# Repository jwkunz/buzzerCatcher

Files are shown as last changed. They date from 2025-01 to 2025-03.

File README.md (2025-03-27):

# 4-Person Buzzer Game  

## Description  

This project includes the hardware design files and source code needed to build a four-person buzzer game from scratch.  

It was created as a volunteer activity associated with [The Church of Jesus Christ of Latter-day Saints](https://churchofjesuschrist.org "Church of Jesus Christ") to teach teenagers how to solder, 3D print, and program in C++.  

You are welcome to use and learn from this project under the **MIT License**.  

---

## How to Play  

1. **Connect the handles** using the RJ12 ports.  
2. **Power on the motherboard** by connecting it to a USB power supply.  
3. The game will play a **startup song**.  
4. The **slide switch toggles sound muting**.  
5. The game starts in the **reset state**—all handle LEDs should be **off**.  
6. **Ask a question.**  
7. Press the **motherboard button** to enable responses—handles will light up the **left LED**.  
8. Players **press and hold a handle button** to respond.  
   - The motherboard will play a sound.  
   - If two players press at the same time, the motherboard applies a **random tiebreaker**.  
   - Players can press the button **before** responses are enabled.  
9. The winning handle will light up the **right LED**.  
10. The player states their **answer**.  
11. **Judge and score manually**.  
12. Press the **motherboard button** to reset and go back to step **6**.  

---

## Code  

### Diagnostics  

Short test scripts for **buttons and LEDs**—useful for teaching coding basics.  

### Game  

The **Arduino project** implementing the game using the **FreeRTOS framework**.  

- Customize the `song_XXXXX` files to add **custom buzzer sounds**.  
- The main file for **Arduino compilation** is `game.ino`.  

---

## 3D Printed Components  

Designed in **FreeCAD**. `.stl` files for 3D printing are available in the corresponding component folders.  

### Case  

A **3D-printable enclosure** for the motherboard.  

### Handle  

A **3D-printable enclosure** for the four handles, each equipped with a button and LEDs. The handles connect to the motherboard via **RJ12 phone cables**.  

---

## PCB Design  

Designed in **KiCad**.  

- The **exports folder** contains:  
  - **Bill of materials (BOM)**  
  - **Gerber and drill files** for PCB manufacturing  
- Also includes:  
  - A `.step` model and **schematic printout** for circuit reference  
- **Note**: This repository does **not** include the full KiCad parts library required for board file recreation.  

---

## Cost Estimate  

At the time of publication:  

- **PCB and component costs**: $75 - $125 USD per board (varies based on order size; e.g., **Osh Park requires a minimum order of 3 PCBs**).  
- **3D printing material**: ~300g of **PLA** per system.  
- **Assembly time**:  
  - **Skilled labor**: ~2 hours  
  - **Beginners**: ~10 hours

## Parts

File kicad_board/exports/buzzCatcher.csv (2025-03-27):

Reference | Datasheet | Qty | Manufacturer_Name | Manufacturer_Part_Number | Description
A1 | http://www.mouser.com/pdfdocs/Gravitech_Arduino_Nano3_0.pdf | 1 |  | ABX00033 | Arduino Nano v3.x
IC1 | https://www.cuidevices.com/product/resource/ts02.pdf | 1 | Same Sky | TS02-66-60-BK-100-SCR-D | Tactile Switches 6 x 6 mm, 6 mm Act Height, 100 gf, Black, Short Crimped, Through Hole, SPST,
J1,J2,J3,J4,J5,J6,J7,J8 | https://datasheet.datasheetarchive.com/originals/distributors/Datasheets_SAMA/df0790d8aebb5882625d0f98b986e00d.pdf | 8 | Molex | 95501-2661 | 6/6 way r/a PCB thru hole data skt,1.5A Molex 6P/6C Right Angle Through Hole Female RJ12 UTP RJ12 Connector
J13,J14,J15,J16 | ~ | 4 |  | BC-66SS025F | RJ connector, 6P6C (6 positions 6 connected)
J17,J18,J19,J20 | https://cdn.amphenol-cs.com/media/wysiwyg/files/drawing/67996.pdf | 4 | Amphenol Communications Solutions | 67996-100HLF | BergStik<sup>&reg;</sup>, Board to Board connector, Unshrouded vertical header, Through Hole, Double Row, 0 Positions, 2.54 mm (0.100in) Pitch
J21 | ~ | 1 |  | UR050-010 | USB Micro Cable
J22 | ~ | 1 |  | PSAA05A-050QL6-R | USB Charger
LED1,LED2,LED3,LED4,LED5,LED6,LED7,LED8 | https://www.kingbrightusa.com/images/catalog/SPEC/WP7113ID5V.pdf | 8 | Kingbright | WP7113ID5V | Red LED with 5V resistor
LED9 | https://www.lumex.com/content/files/ProductAttachment/SSA-LXH1025GD.pdf | 1 | Lumex | SSA-LXH1025GD | LED Circuit Board Indicator LED Circuit Board Indicator Bar - 10 Wide, SIP Green (x 10) Diffused, Tinted 2.2V 25mA Rectangle with Flat Top 5.00mm x 2.50mm Through Hole
LS1 | https://www.cuidevices.com/product/resource/digikeypdf/cmt-1209-590t.pdf | 1 | Same Sky | CMT-1209-590T | Buzzers Transducer, Externally Driven Magnetic 5 V 65mA 2.048kHz 90dB @ 5V, 10cm Through Hole PC Pins
Q1,Q2 | https://datasheet.datasheetarchive.com/originals/distributors/Datasheets-24/DSA-462429.pdf | 2 | onsemi | BS170 | N-channel JFET,BF245A 2mA 30V,BP
R1,R2 | https://www.mouser.ch/datasheet/2/54/4100R-776985.pdf | 2 | Bourns | 4116R-1-121LF | BOURNS - 4116R-1-121LF - Fixed Network Resistor, 120 ohm, 4100R Series, 8 Elements, Isolated, DIP, 16 Pins
RN2 | https://www.bourns.com/data/global/pdfs/4100R.pdf | 1 | Bourns | 4116R-1-103FLF | Resistor Networks & Arrays 10K OHM 16 PIN 1%
S1 | https://www.ckswitches.com/media/1428/os.pdf | 1 | C & K COMPONENTS | OS102011MS2QS1 | SWITCH SLIDE SPDT 100MA 12V
SW1,SW2,SW3,SW4 | ~ | 4 |  | PV5S64019 | Push button switch, generic, two pins

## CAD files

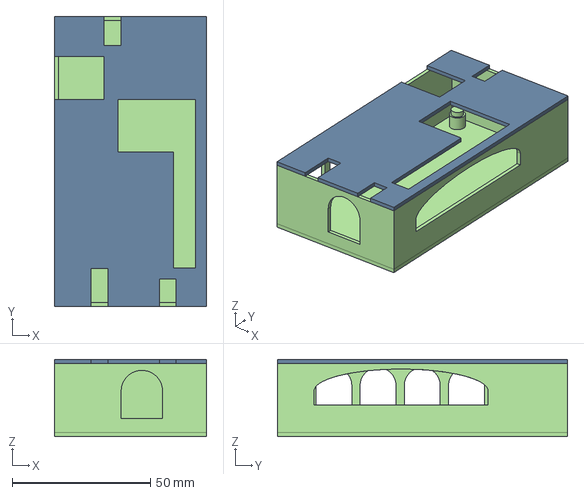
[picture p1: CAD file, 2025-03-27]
freecad_buzzer_case/buzzer_case.FCStd
55.0 x 105.0 x 28.0 mm
Lid

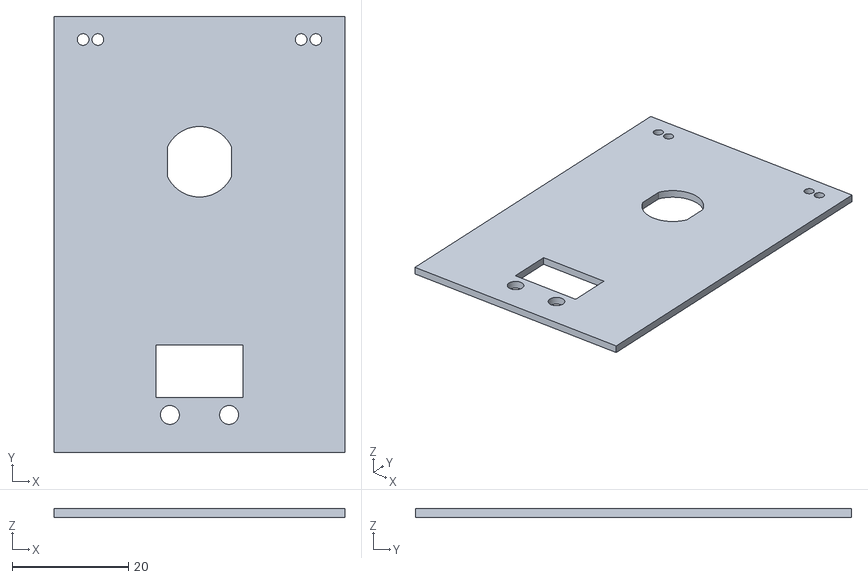
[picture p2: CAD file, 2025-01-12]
freecad_handle/handle-Lid.stl
50.0 x 75.0 x 1.50

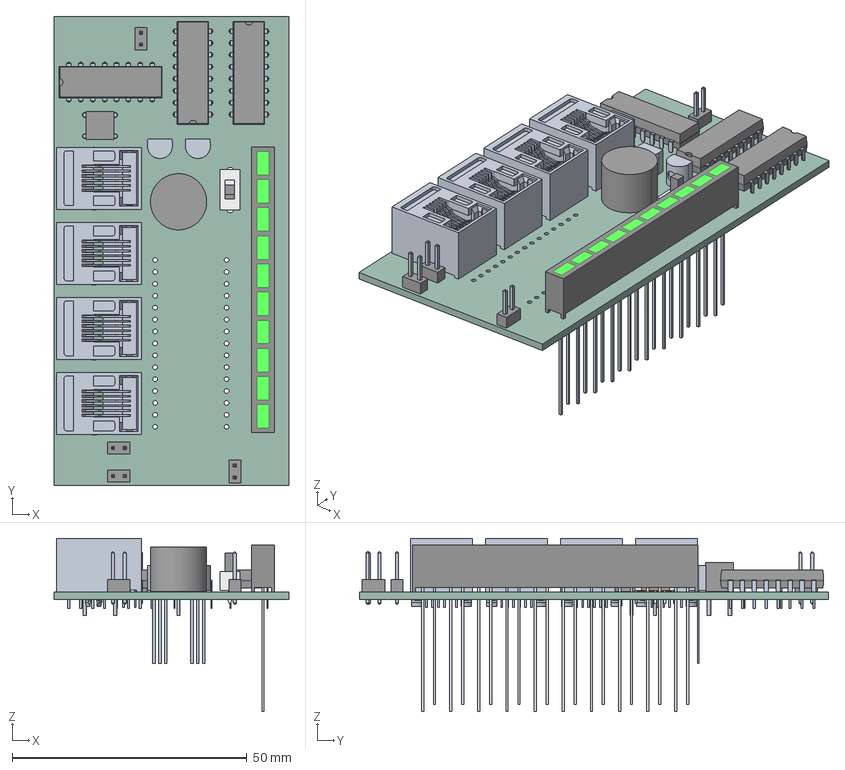
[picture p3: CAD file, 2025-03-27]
kicad_board/exports/buzzCatcher.step
50.0 x 100.0 x 37.0 mm
BC547BBU x 2
ASSEMBLY x 9
OS102011MS2QS1
SSA-LXH1025GD
buzzCatcher_PCB

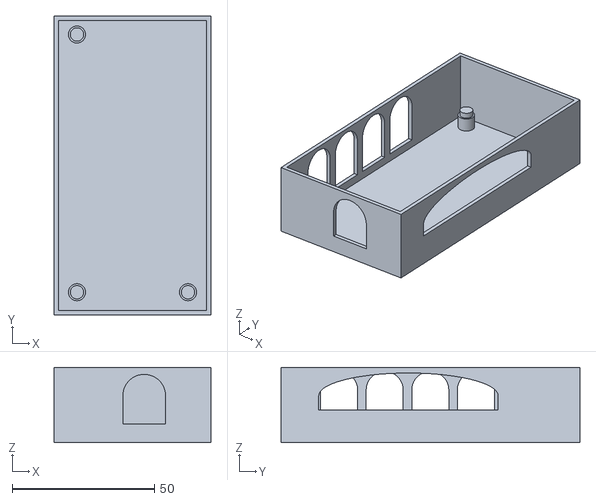
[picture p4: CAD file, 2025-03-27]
freecad_buzzer_case/buzzer_case-Body.stl
55.0 x 105.0 x 26.5

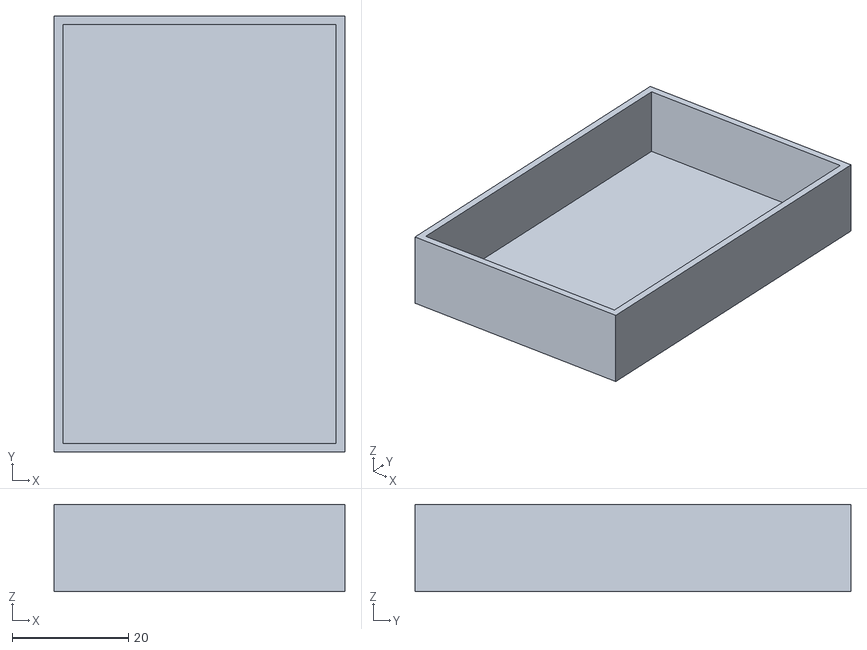
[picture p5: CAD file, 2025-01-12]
freecad_handle/handle-Case.stl
50.0 x 75.0 x 15.0

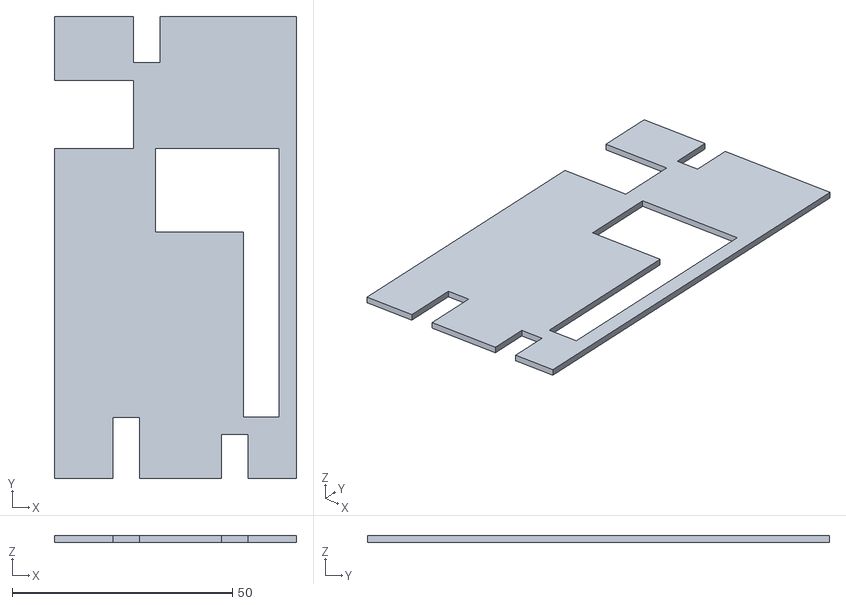
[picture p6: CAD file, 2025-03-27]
freecad_buzzer_case/buzzer_case-Lid.stl
55.0 x 105.0 x 1.50

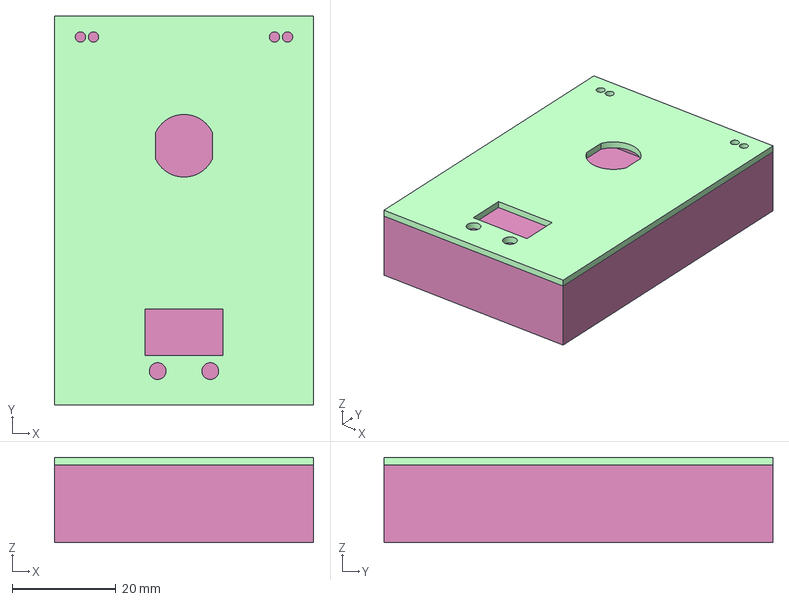
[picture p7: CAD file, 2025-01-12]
freecad_handle/handle.FCStd
50.0 x 75.0 x 16.5 mm
Lid
Case

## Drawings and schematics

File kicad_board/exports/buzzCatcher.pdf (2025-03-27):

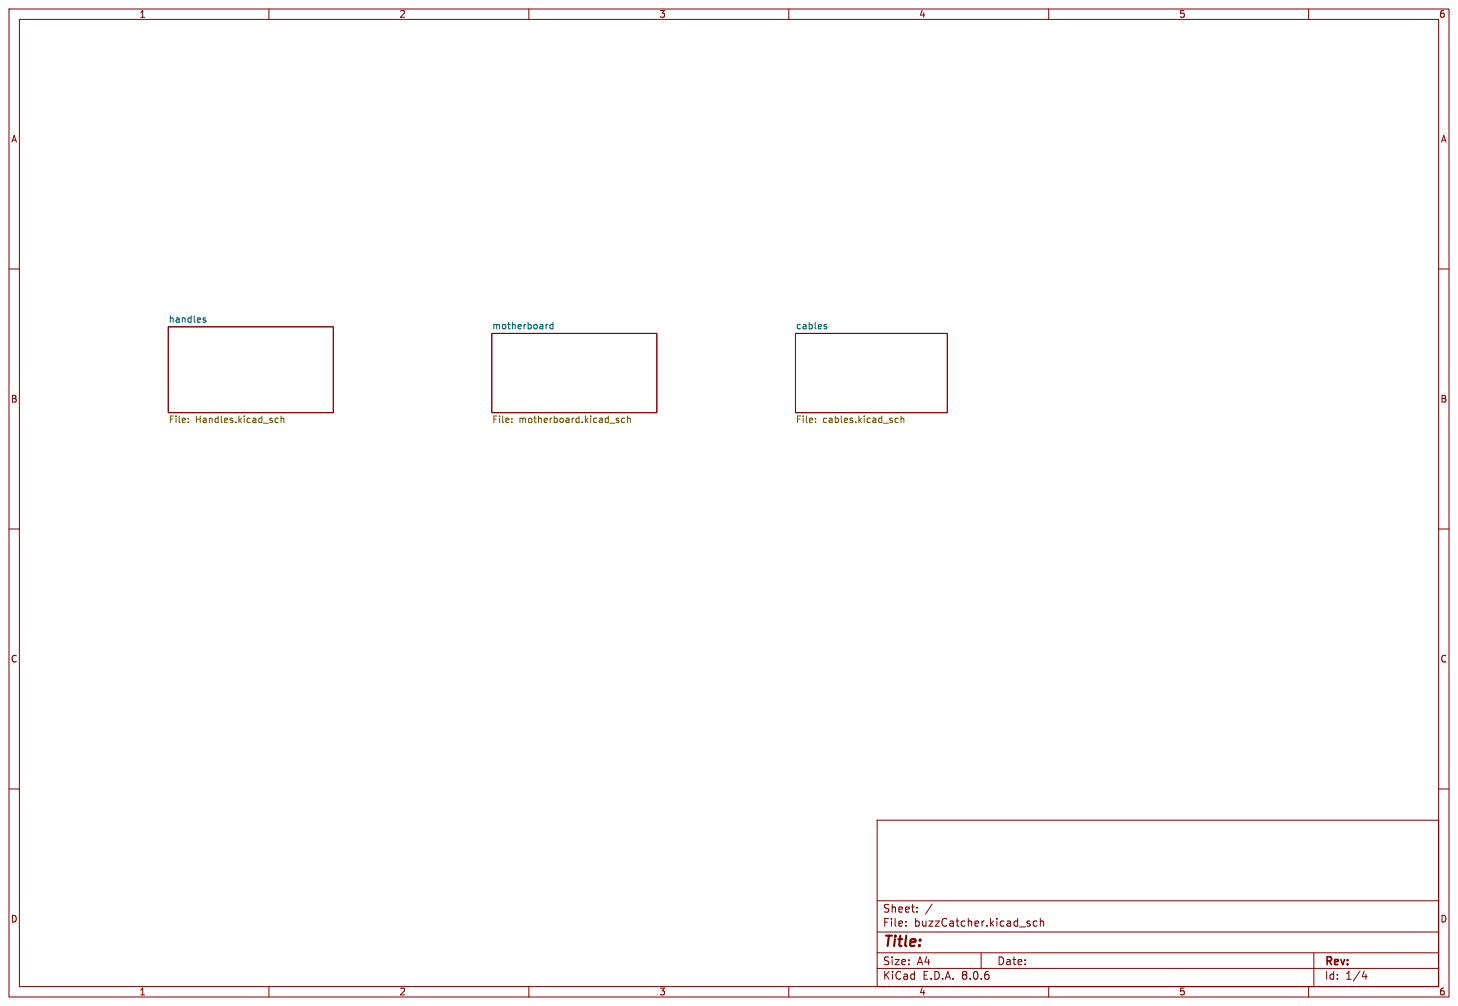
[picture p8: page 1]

Id: 1/4 Title: File: buzzCatcher.kicad_sch Sheet: /

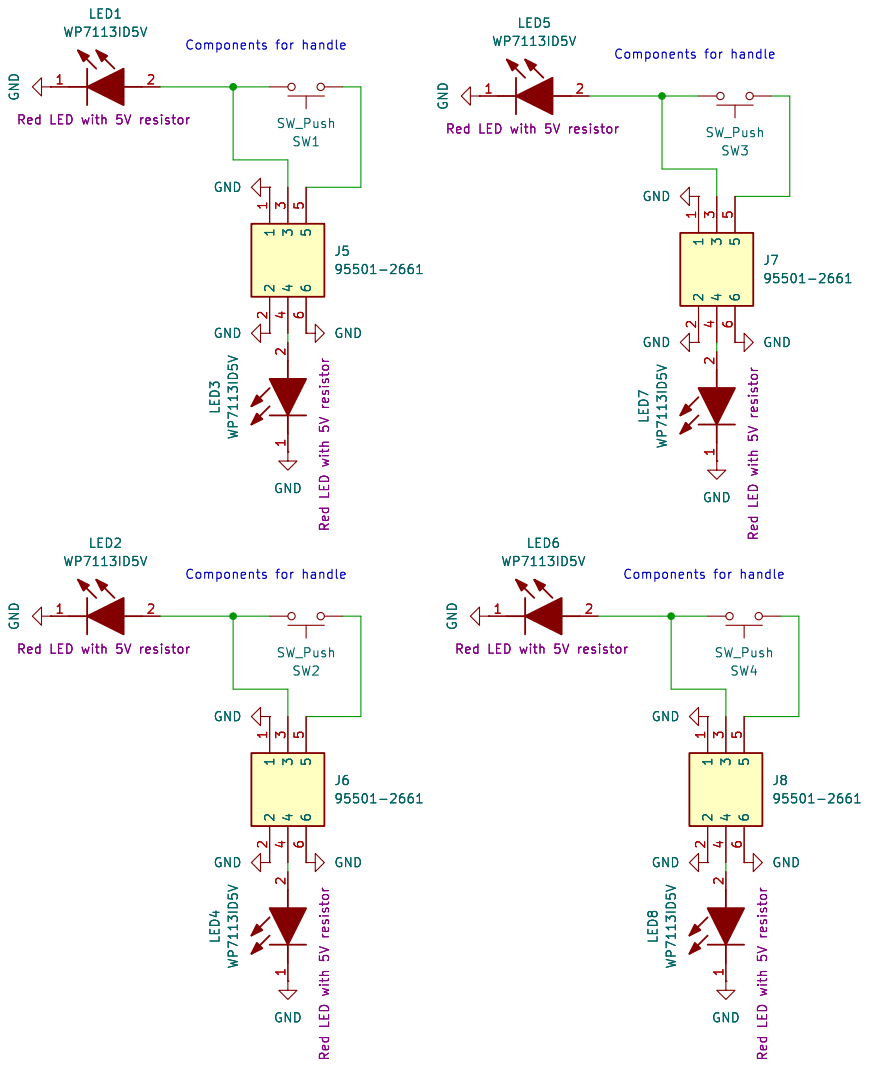
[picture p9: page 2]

Id: 2/4 Title: File: Handles.kicad_sch Sheet: /handles/

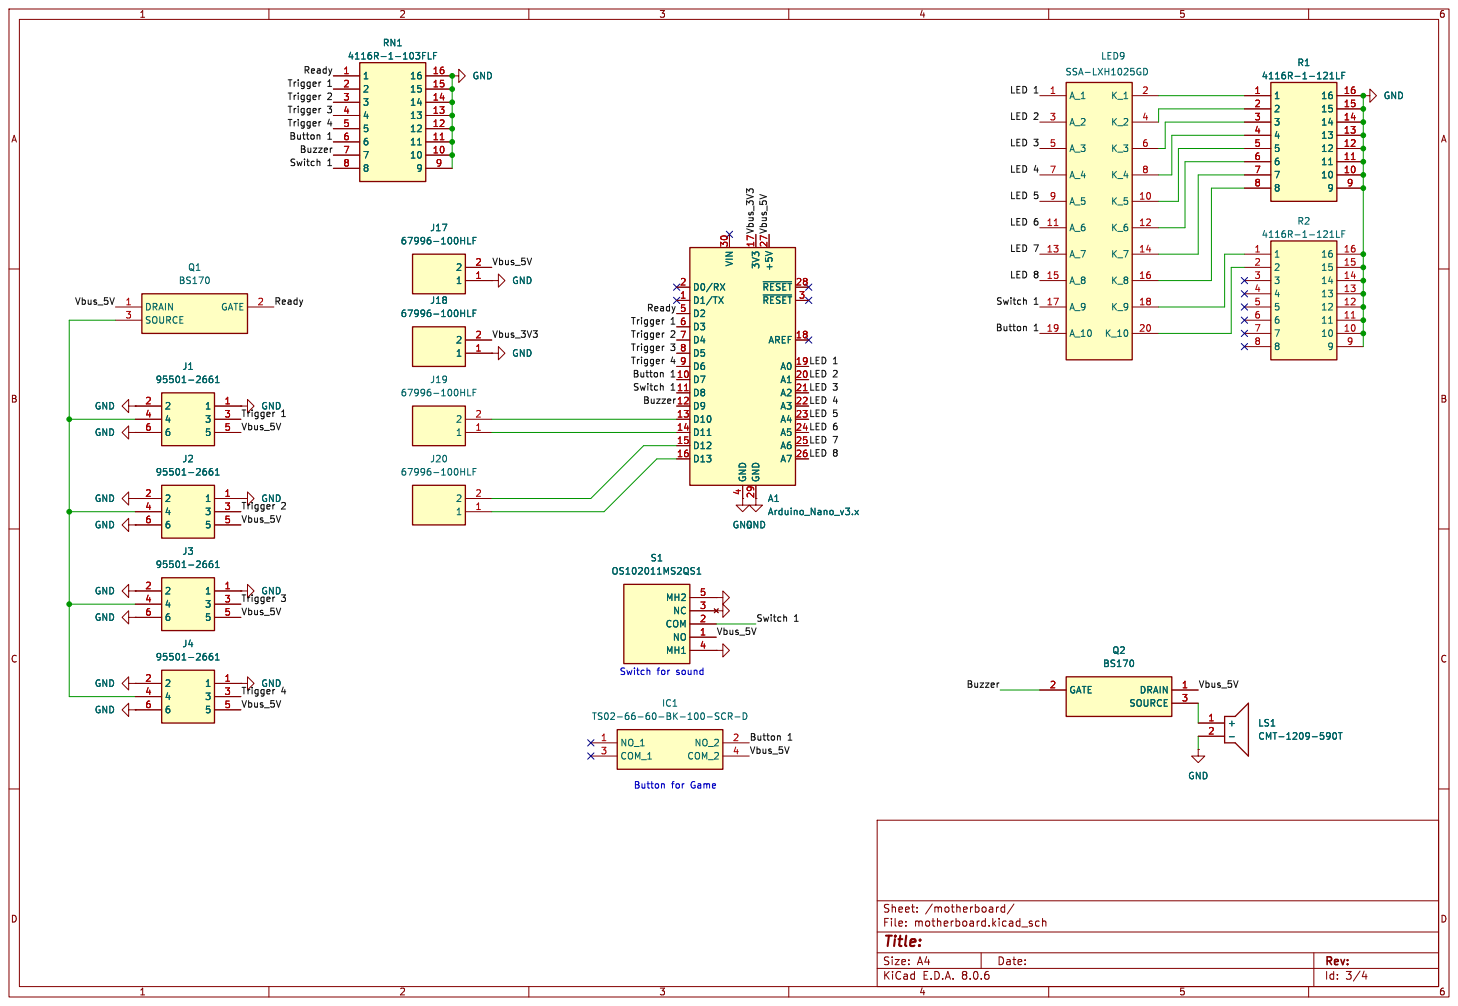
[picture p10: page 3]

Switch for sound Button for Game GND GND GND

Id: 3/4 Title: File: motherboard.kicad_sch Sheet: /motherboard/

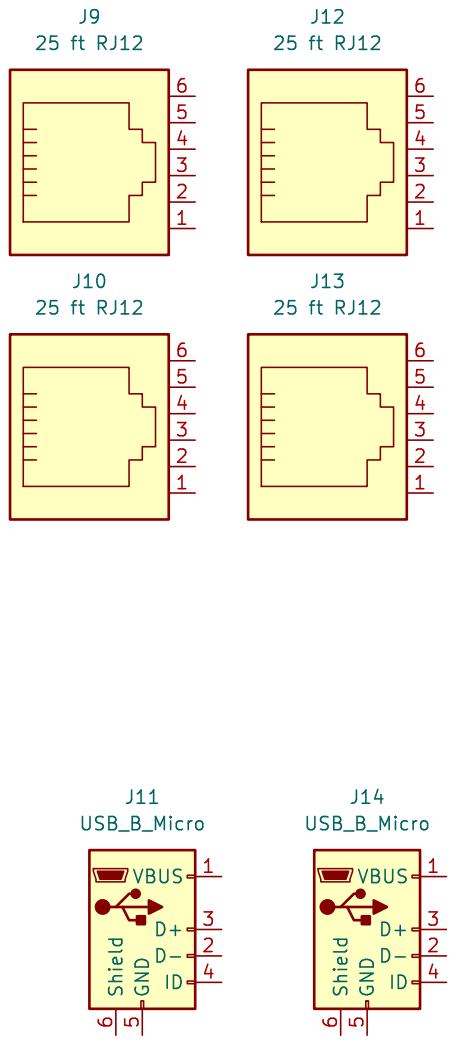
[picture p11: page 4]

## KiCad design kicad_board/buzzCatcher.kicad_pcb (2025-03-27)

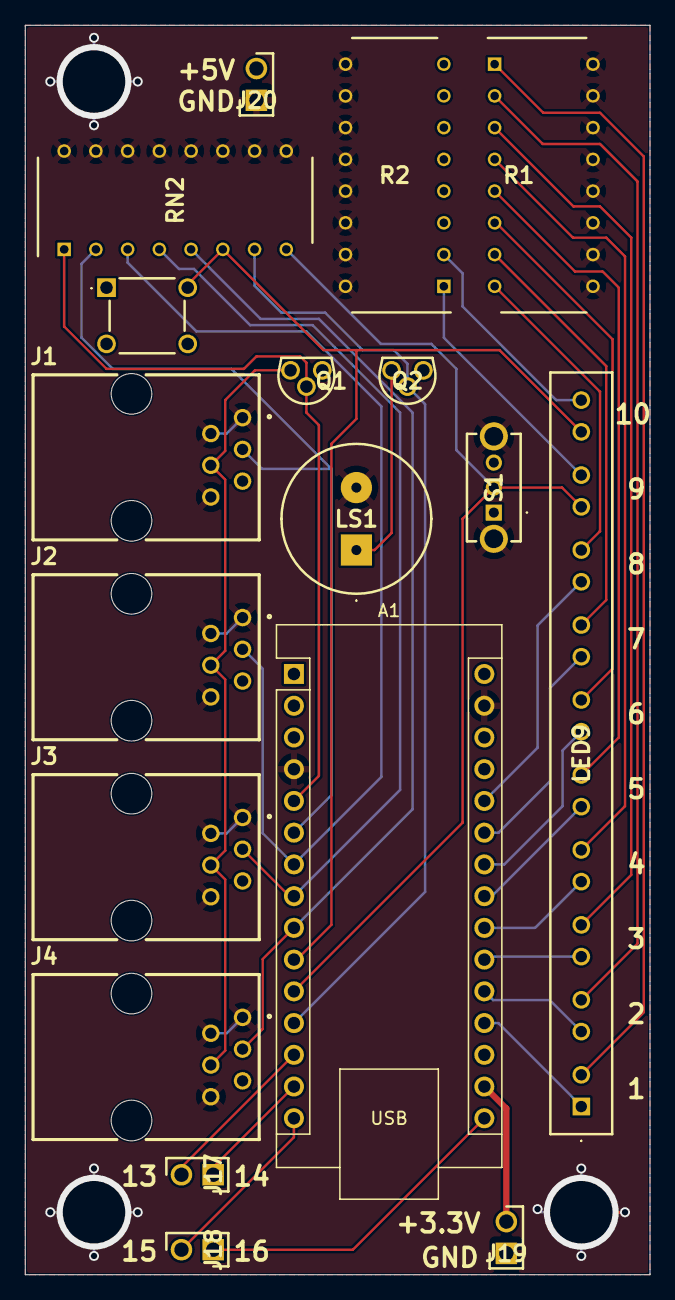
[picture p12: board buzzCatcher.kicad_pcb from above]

Board: 2 copper layers, 50.0 x 100.0 mm, 18 parts (0 on the bottom side), 35 nets.

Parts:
A1: Arduino_Nano_v3.x; Arduino_Nano
IC1: TS02-66-60-BK-100-SCR-D; TS026660BK100SCRD
J1, J2, J3, J4: 95501-2661
J17, J18, J19, J20: 67996-100HLF; HDRV2W67P254_2X1_254X483X858P
LED9: SSA-LXH1025GD; SSALXH1025GD
LS1: CMT-1209-590T; CMT1209590T
Q1, Q2: BS170; LM431ACZ
R1, R2: 4116R-1-121LF; DIP787W49P254L2197H469Q16N
RN2: 4116R-1-103FLF; DIP787W49P254L2197H469Q16N
S1: OS102011MS2QS1

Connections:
/Button 1: A1.10 (D7), IC1.2 (NO_2), LED9.19 (A_10), RN2.6
/Buzzer: A1.12 (D9), Q2.2 (GATE), RN2.7
/LED 1: A1.19 (A0), LED9.1 (A_1)
/LED 2: A1.20 (A1), LED9.3 (A_2)
/LED 3: A1.21 (A2), LED9.5 (A_3)
/LED 4: A1.22 (A3), LED9.7 (A_4)
/LED 5: A1.23 (A4), LED9.9 (A_5)
/LED 6: A1.24 (A5), LED9.11 (A_6)
/LED 7: A1.25 (A6), LED9.13 (A_7)
/LED 8: A1.26 (A7), LED9.15 (A_8)
/Ready: A1.5 (D2), Q1.2 (GATE), RN2.1
/Switch 1: A1.11 (D8), LED9.17 (A_9), RN2.8, S1.2 (COM)
/Trigger 1: A1.6 (D3), J1.3, RN2.2
/Trigger 2: A1.7 (D4), J2.3, RN2.3
/Trigger 3: A1.8 (D5), J3.3, RN2.4
/Trigger 4: A1.9 (D6), J4.3, RN2.5
/Vbus_3V3: A1.17 (3V3), J19.2
/Vbus_5V: A1.27 (+5V), IC1.4 (COM_2), J1.5, J2.5, J3.5, J4.5, J20.2, Q1.1 (DRAIN), Q2.1 (DRAIN), S1.1 (NO)
GND: A1.4 (GND), A1.29 (GND), J1.1, J1.2, J1.6, J2.1, J2.2, J2.6, J3.1, J3.2, J3.6, J4.1, J4.2, J4.6, J19.1, J20.1, LS1.2 (-), R1.9, R1.10, R1.11, R1.12, R1.13, R1.14, R1.15, R1.16, R2.9, R2.10, R2.11, R2.12, R2.13, R2.14, R2.15, R2.16, RN2.9, RN2.10, RN2.11, RN2.12, RN2.13, RN2.14, RN2.15, RN2.16, S1.4 (MH1), S1.5 (MH2)
unnamed: A1.13 (D10), J17.2
unnamed: A1.14 (D11), J17.1
unnamed: A1.15 (D12), J18.2
unnamed: A1.16 (D13), J18.1
unnamed: LED9.2 (K_1), R1.1
unnamed: LED9.4 (K_2), R1.2
unnamed: LED9.6 (K_3), R1.3
unnamed: LED9.8 (K_4), R1.4
unnamed: LED9.10 (K_5), R1.5
unnamed: LED9.12 (K_6), R1.6
unnamed: LED9.14 (K_7), R1.7
unnamed: LED9.16 (K_8), R1.8
unnamed: LED9.18 (K_9), R2.1
unnamed: LED9.20 (K_10), R2.2
unnamed: LS1.1 (+), Q2.3 (SOURCE)
unnamed: J1.4, J2.4, J3.4, J4.4, Q1.3 (SOURCE)

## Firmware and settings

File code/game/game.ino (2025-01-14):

/*
    This file is the top level function for the arduino framework to initialize everything and start the operating system

    Copyright January 2025 Dr. Jakob W. Kunzler
    This file is licensed under the terms of the MIT LICENSE
*/

#define DEBUG_MODE

#include "arduino.h"
#include "pin_map.h"
#include "task_interface.h"
#include "game_task.h"
#include "round_robin_os.h"
#include "loop_speedometer.h"
#include "buzzer_driver.h"

// Determines how long is a stable value on a pin
static const uint32_t micros_for_stable_io = 100000;

// OS
RoundRobinOS<9> RRos;

// Tasks
GameTask GameTasker;
PinDebouncer ButtonDebouncer;
PinDebouncer SwitchDebouncer;
PinDebouncer Trigger0Debouncer;
PinDebouncer Trigger1Debouncer;
PinDebouncer Trigger2Debouncer;
PinDebouncer Trigger3Debouncer;
BuzzerDriver BuzzerDriverTask;

#ifdef DEBUG_MODE
LoopSpeedometer LoopSpeedometerObj;
#endif

// Args
GameTask::TickArgsType GameTaskArgs;

void error_handler(const char *message)
{
  Serial.print("ERROR->");
  Serial.println(message);
  while (true)
  {
  };
}

void print_handler(const char *message)
{
  Serial.print("PRINT->");
  Serial.println(message);
}

void setup()
{
  // Serial monitor
  Serial.begin(115200);

  // Set the pin modes
  pinMode(PIN_READY, OUTPUT);
  pinMode(PIN_TRIGGER_1, INPUT);
  pinMode(PIN_TRIGGER_2, INPUT);
  pinMode(PIN_TRIGGER_3, INPUT);
  pinMode(PIN_TRIGGER_4, INPUT);
  pinMode(PIN_BUTTON, INPUT);
  pinMode(PIN_SWITCH, INPUT);
  pinMode(PIN_BUZZER, OUTPUT);
  pinMode(PIN_IO_0, OUTPUT);
  pinMode(PIN_IO_1, OUTPUT);
  pinMode(PIN_IO_2, OUTPUT);
  pinMode(PIN_IO_3, OUTPUT);
  pinMode(PIN_LED_0, OUTPUT);
  pinMode(PIN_LED_1, OUTPUT);
  pinMode(PIN_LED_2, OUTPUT);
  pinMode(PIN_LED_3, OUTPUT);
  pinMode(PIN_LED_4, OUTPUT);
  pinMode(PIN_LED_5, OUTPUT);
  pinMode(PIN_LED_6, OUTPUT);
  pinMode(PIN_LED_7, OUTPUT);

  // Random init
  randomSeed(analogRead(0));

  // Setup Tasks
  ButtonDebouncer.set(PIN_BUTTON, micros_for_stable_io);

  SwitchDebouncer.set(PIN_SWITCH, micros_for_stable_io);
  Trigger0Debouncer.set(PIN_TRIGGER_1, micros_for_stable_io);
  Trigger1Debouncer.set(PIN_TRIGGER_2, micros_for_stable_io);
  Trigger2Debouncer.set(PIN_TRIGGER_3, micros_for_stable_io);
  Trigger3Debouncer.set(PIN_TRIGGER_4, micros_for_stable_io);

#ifdef DEBUG_MODE
  // Give the tasks human readable names
  ButtonDebouncer.set_name("Button Debouncer");
  Trigger0Debouncer.set_name("Trigger 0 Debouncer");
  Trigger1Debouncer.set_name("Trigger 1 Debouncer");
  Trigger2Debouncer.set_name("Trigger 2 Debouncer");
  Trigger3Debouncer.set_name("Trigger 3 Debouncer");
  GameTasker.set_name("Game Tasker");
  BuzzerDriverTask.set_name("Buzzer");
  LoopSpeedometerObj.set_name("Loop Count Printer");
#endif

  // Call the game task with the required IO args
  GameTask::TickArgsType GameTaskArgs = {
      &ButtonDebouncer,
      &Trigger0Debouncer,
      &Trigger1Debouncer,
      &Trigger2Debouncer,
      &Trigger3Debouncer,
      &BuzzerDriverTask};

  // Call the game task with the required IO args
  BuzzerDriver::TickArgsType BuzzTaskArgs = {
      &SwitchDebouncer};

  // Load up the scheduler
  RRos.push_task(&ButtonDebouncer, NULL);
  RRos.push_task(&SwitchDebouncer, NULL);
  RRos.push_task(&Trigger0Debouncer, NULL);
  RRos.push_task(&Trigger1Debouncer, NULL);
  RRos.push_task(&Trigger2Debouncer, NULL);
  RRos.push_task(&Trigger3Debouncer, NULL);
  RRos.push_task(&GameTasker, (void *)&GameTaskArgs);
  RRos.push_task(&BuzzerDriverTask, (void *)&BuzzTaskArgs);

#ifdef DEBUG_MODE
  // /Count the loop speed
  RRos.push_task(&LoopSpeedometerObj, NULL);
  print_handler("Finished hardware initialization");
#endif

  // Printing
  RRos.set_print_handler_functions(&print_handler);
  // Errors
  RRos.set_error_handler_functions(&error_handler);
}

void loop()
{
  // Round Robin scheduling
  RRos.tick();
}

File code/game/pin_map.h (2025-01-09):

/*
    These are the pins of the arduino nano on the buzzer control board

    Copyright January 2025 Dr. Jakob W. Kunzler
    This file is licensed under the terms of the MIT LICENSE
*/

#pragma once
#define PIN_READY 2
#define PIN_TRIGGER_1 3
#define PIN_TRIGGER_2 4
#define PIN_TRIGGER_3 5
#define PIN_TRIGGER_4 6
#define PIN_BUTTON 7
#define PIN_SWITCH 8
#define PIN_BUZZER 9
#define PIN_IO_0 11
#define PIN_IO_1 10
#define PIN_IO_2 12
#define PIN_IO_3 13
#define PIN_LED_0 14
#define PIN_LED_1 15
#define PIN_LED_2 16
#define PIN_LED_3 17
#define PIN_LED_4 18
#define PIN_LED_5 19
#define PIN_LED_6 20
#define PIN_LED_7 21

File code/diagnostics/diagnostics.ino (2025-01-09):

#include "pin_map.h"

void setup() {
  // put your setup code here, to run once:
  pinMode(PIN_READY, OUTPUT);
  pinMode(PIN_TRIGGER_1, OUTPUT);
  pinMode(PIN_TRIGGER_2, OUTPUT);
  pinMode(PIN_TRIGGER_3, OUTPUT);
  pinMode(PIN_TRIGGER_4, OUTPUT);
  pinMode(PIN_BUTTON, OUTPUT);
  pinMode(PIN_SWITCH, OUTPUT);
  pinMode(PIN_BUZZER, OUTPUT);
  pinMode(PIN_IO_0, OUTPUT);
  pinMode(PIN_IO_1, OUTPUT);
  pinMode(PIN_IO_2, OUTPUT);
  pinMode(PIN_IO_3, OUTPUT);
  pinMode(PIN_LED_0, OUTPUT);
  pinMode(PIN_LED_1, OUTPUT);
  pinMode(PIN_LED_2, OUTPUT);
  pinMode(PIN_LED_3, OUTPUT);
  pinMode(PIN_LED_4, OUTPUT);
  pinMode(PIN_LED_5, OUTPUT);
  pinMode(PIN_LED_6, OUTPUT);
  pinMode(PIN_LED_7, OUTPUT);

  Serial.begin(250000);
}

void buzzer() {
  Serial.println("Buzzer Diagnostic:\nListen for a 1 KHz tone\nPress 0 to cancel.\n");
  bool continue_flag = true;
  bool buzzer_state = false;
  const uint16_t frequency_hz = 1000;
  const uint16_t delay_us = 1000000 / frequency_hz;
  while (continue_flag) {
    uint8_t byte = Serial.read();
    switch (byte) {
      case '0':
        {
          return;
          break;
        }
      default:
        {
          break;
        }
    }
    digitalWrite(PIN_BUZZER, buzzer_state);
    buzzer_state = !buzzer_state;
    delayMicroseconds(delay_us);
  }
}

void leds() {
  Serial.println("LED Diagnostic:\nLEDs should all be cycling with 1 second each\nPress 0 to cancel.\n");
  bool continue_flag = true;
  const uint16_t delay_ms = 1000;
  int pin_number = 0;
  const int n_pins = 8;
  const int led_pins[n_pins] = { PIN_LED_0, PIN_LED_1, PIN_LED_2, PIN_LED_3, PIN_LED_4, PIN_LED_5, PIN_LED_6, PIN_LED_7 };
  while (continue_flag) {
    uint8_t byte = Serial.read();
    switch (byte) {
      case '0':
        {
          return;
          break;
        }
      default:
        {
          break;
        }
    }
    digitalWrite(led_pins[pin_number], true);
    delay(delay_ms);
    digitalWrite(led_pins[pin_number], false);
    pin_number = (pin_number + 1) % n_pins;
  }
}

void main_buttons_switch() {
  Serial.println("Main button and swtich diagnostic:\nPress 0 to cancel.\n");
  bool continue_flag = true;
  const uint16_t delay_ms = 1000;
  while (continue_flag) {
    uint8_t byte = Serial.read();
    switch (byte) {
      case '0':
        {
          return;
          break;
        }
      default:
        {
          break;
        }
    }
    bool switch_state = digitalRead(PIN_SWITCH);
    bool button_state = digitalRead(PIN_BUTTON);
    char print_str[32];
    sprintf(print_str, "Button: %u, Switch: %u \n", button_state, switch_state);
    Serial.println(print_str);
    delay(delay_ms);
  }
}

void trigger_test() {
  Serial.println("Trigger Test\nPress 0 to cancel.\n");
  bool continue_flag = true;
  uint8_t trigger_state = 0;
  while (continue_flag) {
    uint8_t byte = Serial.read();
    switch (byte) {
      case '0':
        {
          return;
          break;
        }
      default:
        {
          break;
        }
    }

    switch (trigger_state) {
      case 0:
        {
          digitalWrite(PIN_READY, HIGH);
          trigger_state += 1;
          Serial.println("Placed the ready HIGH.  Waiting for press from user 1");
          break;
        }
      case 1:
        {
          if (digitalRead(PIN_TRIGGER_1) == HIGH) {
            Serial.println("Got Trigger 1 and now waiting for Trigger 2");
            trigger_state += 1;
          }
          break;
        }
      case 2:
        {
          if (digitalRead(PIN_TRIGGER_2) == HIGH) {
            Serial.println("Got Trigger 2 and now waiting for Trigger 3");
            trigger_state += 1;
          }
          break;
        }
      case 3:
        {
          if (digitalRead(PIN_TRIGGER_3) == HIGH) {
            Serial.println("Got Trigger 3 and now waiting for Trigger 4");
            trigger_state += 1;
          }
          break;
        }
      case 4:
        {
          if (digitalRead(PIN_TRIGGER_4) == HIGH) {
            Serial.println("Got Trigger 4");
            trigger_state += 1;
          }
          break;
        }
      default:
        {
          digitalWrite(PIN_READY, LOW);
          continue_flag = false;
          break;
        }
    }
  }
}

void loop() {
  Serial.println("\n\nDiagnostic mode\nEnter number for a command\n0-Cancel/Quit Operation\n1-Buzzer\n2-LEDs\n3-Main Button and Switch\n4-Trigger Test\n");
  bool continue_flag = true;
  while (continue_flag) {
    uint8_t byte = Serial.read();
    switch (byte) {
      case '0':
        {
          continue_flag = false;
          break;
        }
      case '1':
        {
          buzzer();
          continue_flag = false;
          break;
        }
      case '2':
        {
          leds();
          continue_flag = false;
          break;
        }
      case '3':
        {
          main_buttons_switch();
          continue_flag = false;
          break;
        }
      case '4':
        {
          trigger_test();
          continue_flag = false;
          break;
        }
      default:
        {
          break;
        }
    }
  }
}

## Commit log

2024-11-12 First draft schematic
    [buzzCatcher.kicad_pcb, buzzCatcher.kicad_sch]
2024-11-12 First draft routing
    [buzzCatcher.kicad_pcb, buzzCatcher.kicad_sch]
2024-11-12 Some modifications during quoting
    [buzzCatcher.csv, buzzCatcher.kicad_sch]
2024-11-15 Smaller and cheaper
    [buzzCatcher.kicad_pcb]
2024-11-22 More compact draft
    [buzzCatcher.kicad_pcb]
2024-11-22 Added handle parts
    [buzzCatcher.csv, buzzCatcher.kicad_pcb, buzzCatcher.kicad_sch]
2024-11-23 Moved to kicad folder
    [buzzCatcher.csv, buzzCatcher.kicad_pcb, buzzCatcher.kicad_sch]
2024-11-23 Added handle mechanical design
    [handle.FCStd]
2024-11-27 Arduino version
    [buzzCatcher.csv, buzzCatcher.kicad_pcb, buzzCatcher.kicad_sch]
2024-11-27 Adjusted hold spots for RJ12 connector
    [handle.FCStd]
2024-12-17 Added break out headers
    [buzzCatcher.csv, buzzCatcher.kicad_pcb, buzzCatcher.kicad_sch]
2024-12-17 Converted to bigger resistor pack
    [buzzCatcher.kicad_pcb, buzzCatcher.kicad_sch]
2024-12-17 Updated BOM
    [buzzCatcher.csv]
2024-12-19 Compacted to 100 x 50 mm
    [buzzCatcher.kicad_pcb]
2024-12-24 Added pin debouncer
2024-12-30 Adjusted the rtos framework
2024-12-31 Added some linting fixes
    [game_task.h, main.ino]
2025-01-04 Fixed Version 1.0 button pin error
    [buzzCatcher.kicad_pcb, buzzCatcher.kicad_sch]
2025-01-09 Made adjustements to handle after first draft fab
    [handle-Case.stl, handle-Lid.stl, handle.FCStd]
2025-01-10 Added the buzzer case cad
    [buzzer_case-Body.stl, buzzer_case-Lid.stl, buzzer_case.FCStd]
2025-01-10 Added feature where the buzzer indicates the person who answered
    [game_task.h]
2025-01-11 Reimplemented the printing without using String()
2025-01-11 Fixed thickness of lid
    [handle-Lid.stl, handle.FCStd]
2025-01-12 Removed screws from handle
    [handle-Case.stl, handle-Lid.stl, handle.FCStd]
2025-01-13 Added buzzer driver. Game not working at this commit
    [game.ino, game_task.h, song_response.h]
2025-03-27 Final tweaks after fabrication
    [buzzCatcher.csv, buzzCatcher.kicad_sch, buzzer_case-Body.stl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]
2025-03-27 Added manufacturing outputs
    [Handles.kicad_sch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]
